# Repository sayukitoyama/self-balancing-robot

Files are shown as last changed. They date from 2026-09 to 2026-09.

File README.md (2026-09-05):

# Self-Balancing Robot

This project is a two-wheel self-balancing robot designed and built using an ESP32, an MPU-6050 inertial measurement unit, and a TB6612FNG motor driver. The robot uses accelerometer and gyroscope data from the MPU-6050 to estimate its tilt angle in real time.

The estimated tilt angle is compared with the desired upright position, and a PID controller calculates the motor output needed to correct the robot's motion. The TB6612FNG motor driver controls two DC gear motors that move the wheels in response to the controller output.

## Mechanical Design

The robot chassis and drive components were modeled in CAD to support the motors, electronics, and wheel assembly. Custom components were designed around the dimensions of the physical hardware and incorporated into the final prototype.

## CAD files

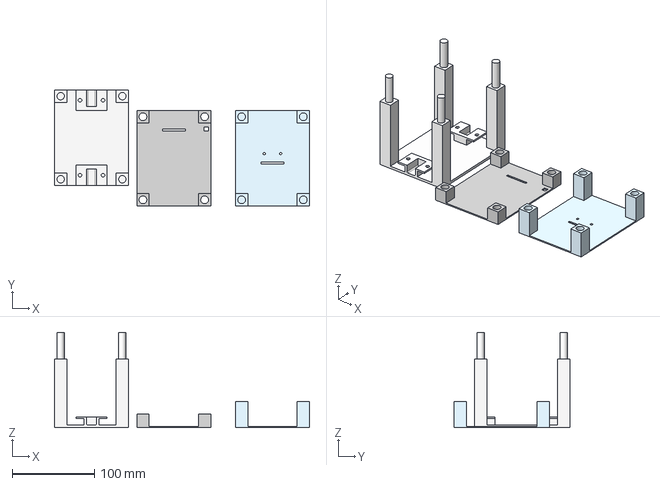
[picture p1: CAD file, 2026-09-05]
robot_chassis.step
310.0 x 141.0 x 115.5 mm

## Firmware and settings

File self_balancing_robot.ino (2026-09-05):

#include <Wire.h>

const int MPU_ADDR = 0x68;

int accX, accY, accZ;
int gyroX, gyroY, gyroZ;

float angle = 0;  //robot tilt angle in degrees 
float gyroOffset = 0;  //offset of gyroscope

//Values of the pins
const int PWMA = 25;
const int AIN1 = 26;
const int AIN2 = 27;
const int PWMB = 33;
const int BIN1 = 32;
const int BIN2 = 23;
const int STBY = 14;

float targetAngle = 0;  //what the PID control will angle at
float pro = 50;  //The P of PID
float inte = 0.5;  //The I
float der = 1.75;  //The D
float integral = 0;  //Value for the integral to add the erorr up
float fallAngle = 13;  //The max angle the robot can turn until it hits the ground
int maxP = 255;  //The max power (The motor driver can reach)
int minP = 10;  //The min power (The motor driver can reach)
long lastTime = 0;

void setup() 
{

  Serial.begin(115200);
  setupMotors();
  Wire.begin(21, 22);
  Wire.setClock(50000);
  Wire.setTimeOut(10);  //timeout if MPU does respond after 10ms just for safety
  setupMPU();
  delay(300);  //sometimes was bugging out without delay
  calibrateGyro();

  readMPU();
  angle = getAng();  //gets the initial angle

  lastTime = micros();

  Serial.println("start");

}

void loop()
{
  
  long now = micros();
  float dt = (now - lastTime) / 1000000.0;  //gets time it took from running the last loop function in seconds
  lastTime = now;
  readMPU();
  float accAngle = getAng();
  float gyroRate = (gyroX / 131.0) - gyroOffset;
  angle = 0.98 * (angle + gyroRate * dt) + 0.02 * accAngle;  //uses both data from gyro and accelerometer to find a more accurate angle of the robot

  if (abs(angle) > fallAngle)  //stops if the robot tilts too much
  {
    integral = 0;
    stopMotors();
    return;
  }

  float error = targetAngle - angle;
  float P = pro * error;
  integral += error * dt;
  float I = inte * integral;
  float D = -der * gyroRate;

  float output = P + I + D;

  output = constrain(output, -maxP, maxP);  //limits it between the actual value the motor driver can go

  setBothMotors((int)output);

}

void setupMPU()
{

  Wire.beginTransmission(MPU_ADDR);  //wake MPU from sleep mode
  Wire.write(0x6B);
  Wire.write(0);
  Wire.endTransmission(true);  

  Wire.beginTransmission(MPU_ADDR);  //setup gyro to +-250 degrees
  Wire.write(0x1B);
  Wire.write(0x00);
  Wire.endTransmission(true);

  Wire.beginTransmission(MPU_ADDR);  //set up accelerometer to +-2g
  Wire.write(0x1C);
  Wire.write(0x00);
  Wire.endTransmission(true);

}

void readMPU() {

  Wire.beginTransmission(MPU_ADDR);
  Wire.write(0x3B);
  Wire.endTransmission(false);
  Wire.requestFrom(MPU_ADDR, 14, true);
  
  accX = Wire.read() << 8 | Wire.read();
  accY = Wire.read() << 8 | Wire.read();
  accZ = Wire.read() << 8 | Wire.read();

  Wire.read();  //skips temperature reading
  Wire.read();

  gyroX = Wire.read() << 8 | Wire.read();
  gyroY = Wire.read() << 8 | Wire.read();
  gyroZ = Wire.read() << 8 | Wire.read();

}

float getAng() 
{

  return atan2(accY, accZ) * 180.0 / PI;
}

void calibrateGyro()
{

  float sum = 0;

  const int samples = 1000;

  Serial.println("keep robot still...");

  for (int i = 0; i < samples; i++) 
  {

    readMPU();
    sum += gyroX / 131.0;
    delay(2);

  }

  gyroOffset = sum / samples;

  Serial.print("Gyro offset: ");
  Serial.println(gyroOffset);

}

void setupMotors()
{

  pinMode(AIN1, OUTPUT);
  pinMode(AIN2, OUTPUT);

  pinMode(BIN1, OUTPUT);
  pinMode(BIN2, OUTPUT);

  pinMode(STBY, OUTPUT);

  digitalWrite(STBY, HIGH);

  ledcAttach(PWMA, 20000, 8);
  ledcAttach(PWMB, 20000, 8);

  stopMotors();
}

void setBothMotors(int power)
{

  power = constrain(power, -255, 255);

  if (abs(power) < minP) {
    power = 0;
  }

  setLeftMotor(power);
  setRightMotor(-power);  //This is reversed becaused I made it so that the motors are not facing the same direction

}

void setLeftMotor(int power)
{

  power = constrain(power, -255, 255);

  if (power > 0)
  {

    digitalWrite(AIN1, HIGH);
    digitalWrite(AIN2, LOW);
    ledcWrite(PWMA, power);

  } 
  else if (power < 0)
  {

    digitalWrite(AIN1, LOW);
    digitalWrite(AIN2, HIGH);
    ledcWrite(PWMA, -power);

  }
  else
  {

    digitalWrite(AIN1, LOW);
    digitalWrite(AIN2, LOW);
    ledcWrite(PWMA, 0);
  
  }
}

void setRightMotor(int power) {

  power = constrain(power, -255, 255);

  if (power > 0) 
  {

    digitalWrite(BIN1, HIGH);
    digitalWrite(BIN2, LOW);
    ledcWrite(PWMB, power);

  } 
  else if (power < 0)
  {

    digitalWrite(BIN1, LOW);
    digitalWrite(BIN2, HIGH);
    ledcWrite(PWMB, -power);

  }
  else
  {

    digitalWrite(BIN1, LOW);
    digitalWrite(BIN2, LOW);
    ledcWrite(PWMB, 0);

  }
}

void stopMotors() 
{

  setLeftMotor(0);
  setRightMotor(0);

}
